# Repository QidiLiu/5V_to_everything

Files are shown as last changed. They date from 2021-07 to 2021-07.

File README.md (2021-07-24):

# 5V_to_everything

Convert *5V (from microUSB)* to various *positive and negative voltages* (for **small currents** only) at low cost with the TPS61040.

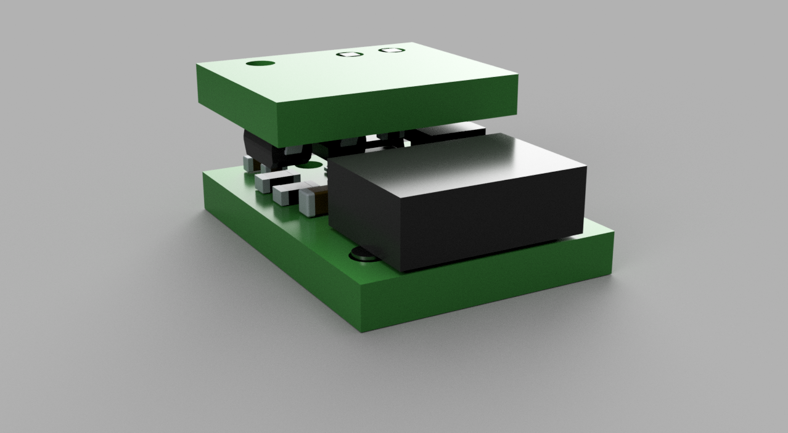
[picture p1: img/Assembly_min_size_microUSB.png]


## Low cost version

### Setting and Usage

Most smartphone chargers can convert 220VAC to 5VDC. With this "5V_to_every" converter, electronic engineers can easily get a positive and negative voltage source, which has an **output voltage from ±5V to ±24V** using their smartphone chargers.

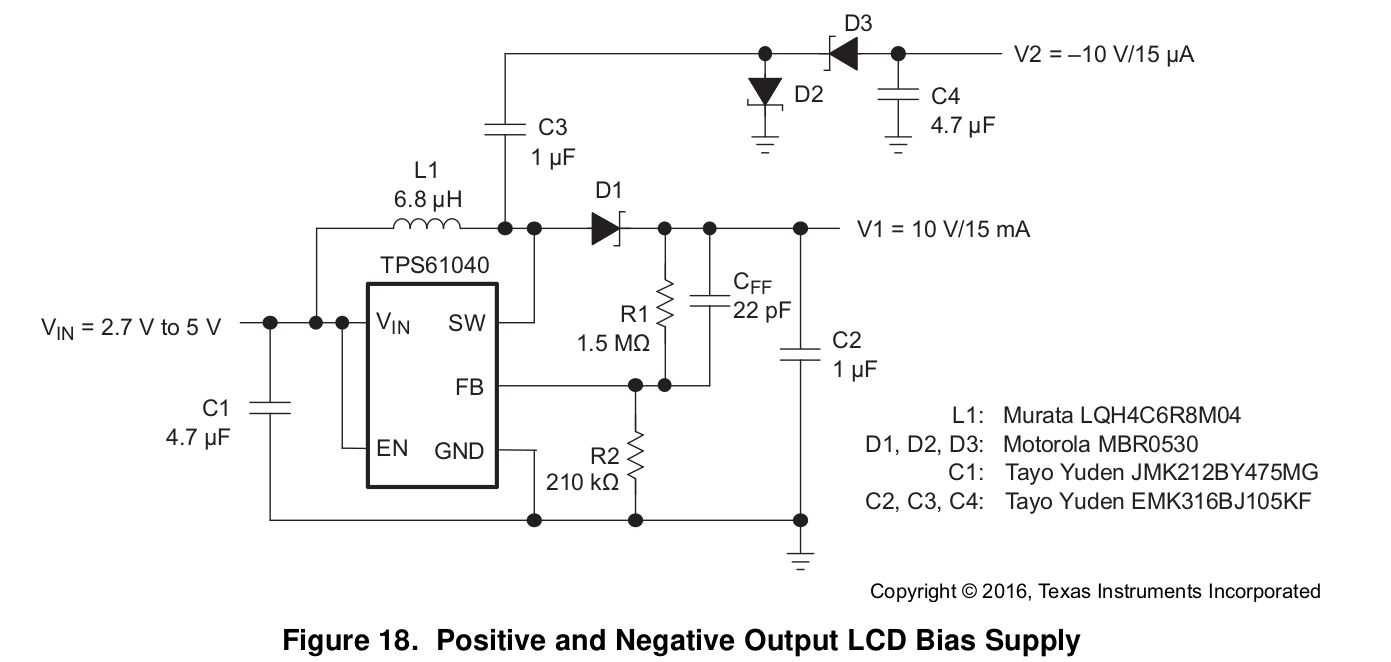
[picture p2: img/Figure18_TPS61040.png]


The basic idea comes from [datasheet of TPS61040](https://www.ti.com/lit/ds/symlink/tps61040.pdf). The output voltage can configured by changing the ratio of R1 to R2. In my design, R2 is 1kΩ SMD resistor and R1 can be easily replaced with a suitable resistor accourding to the calculation:

V_out = 1.233V × (1 + R1/R2) 

(V+ = V_out; V- = -V_out)

(range of V_out: 5V~24V)

For example, if you want a ±10V voltage source:

10 = 1.233 × (1 + R1/1000)

→ R1 = 7110 [Ω]

That means you should replace R1 with a 7.1kΩ resistor.

I also recommend you to replace R1 with a **potentiometer (20kΩ)**, so you can adjust the output voltage directly by hand, and reuse this voltage source in different projects, even when they demand different voltages.

## Minimum size version with microUSB

min_size_microUSB is a minimum size version of 5V_to_everything.

Size of min_size_microUSB[mm]: **14 x 10 x 6**

## Planned versions

- Minimum size version with typeC

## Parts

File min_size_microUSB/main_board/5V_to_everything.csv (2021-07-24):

Reference | Value | Footprint | Datasheet | Description | Height | Manufacturer_Name | Manufacturer_Part_Number | Arrow Part Number | Arrow Price/Stock | Mouser Part Number | Mouser Price/Stock
J1 | MICROXNJ | my_lib:MICROXNJ | https://datasheet.lcsc.com/szlcsc/1912111437_SHOU-HAN-MicroXNJ_C404969.pdf | MICRO-USB-SMD_MICROXNJ | 2.425 | Shou Han | MICROXNJ
C1 | CL10A106MQ8NNNC | my_lib:CAPC1608X90N | http://uk.rs-online.com/web/p/products/7664718 | Samsung Electro-Mechanics 10uF Multilayer Ceramic Capacitor MLCC 6.3V dc +/-20% X5R Dielectric 0603 (1608M) SMD | 0.9 | Samsung Electro-Mechanics | CL10A106MQ8NNNC | CL10A106MQ8NNNC | https://www.arrow.com/en/products/cl10a106mq8nnnc/samsung-electro-mechanics | 187-CL10A106MQ8NNNC | https://www.mouser.co.uk/ProductDetail/Samsung-Electro-Mechanics/CL10A106MQ8NNNC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
L1 | LQH32CN4R7M33L | my_lib:LQH32DN100K23L | https://psearch.en.murata.com/inductor/product/LQH32CN4R7M33%23.html | Murata LQH32CN Series Wire-wound SMD Inductor 4.7 uH +/-20% 650mA Idc | 2.2 | Murata Electronics | LQH32CN4R7M33L | LQH32CN4R7M33L | https://www.arrow.com/en/products/lqh32cn4r7m33l/murata-manufacturing | 81-LQH32CN4R7M33L | https://www.mouser.co.uk/ProductDetail/Murata-Electronics/LQH32CN4R7M33L/?qs=Nd4APhAyBuHM6RzmYPrpQA%3D%3D
D1 | MBR0520L | my_lib:SOD3816X128N | https://www.onsemi.com/pub/Collateral/MBR0520L-D.pdf | ON Semi MBR0520L SMT Schottky Diode, 20V 500mA, 2-Pin SOD-123 | 1.28 | ON Semiconductor | MBR0520L | MBR0520L | https://www.arrow.com/en/products/mbr0520l/on-semiconductor | 512-MBR0520L | https://www.mouser.co.uk/ProductDetail/ON-Semiconductor-Fairchild/MBR0520L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
R2 | 0603WAF1001T5E | my_lib:RESC1608X55N | https://datasheet.lcsc.com/szlcsc/Uniroyal-Elec-0603WAF1001T5E_C21190.pdf | 1k +/-1% 0.1W +/-100ppm/ 0603 Chip Resistor - Surface Mount | 0.55 | UNI-ROYAL(Uniroyal Elec) | 0603WAF1001T5E
C2 | CC0402JRNPO9BN220 | my_lib:CAPC1005X55N | http://www.yageo.com/documents/recent/UPY-GP_NP0_16V-to-50V_16.pdf | YAGEO - CC0402JRNPO9BN220 - CAP, 22PF, 50V, 5%, C0G/NP0, 0402 | 0.55 | YAGEO (PHYCOMP) | CC0402JRNPO9BN220 | CC0402JRNPO9BN220 | https://www.arrow.com/en/products/cc0402jrnpo9bn220/yageo | 603-CC402JRNPO9BN220 | https://www.mouser.co.uk/ProductDetail/Yageo/CC0402JRNPO9BN220?qs=AgBp2OyFlx9i3sVl6vpnFQ%3D%3D
C3 | CL05A105KA5NQNC | my_lib:CAPC1005X60N | https://www.arrow.com/en/products/cl05a105ka5nqnc/samsung-electro-mechanics | Cap Ceramic 1uF 25V X5R 10% Pad SMD 0402 85C T/R | 0.6 | Samsung Electro-Mechanics | CL05A105KA5NQNC | CL05A105KA5NQNC | https://www.arrow.com/en/products/cl05a105ka5nqnc/samsung-electro-mechanics | 187-CL05A105KA5NQNC | https://www.mouser.co.uk/ProductDetail/Samsung-Electro-Mechanics/CL05A105KA5NQNC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
IC1 | TPS61040DBVR | my_lib:SOT95P280X145-5N | http://www.ti.com/lit/ds/symlink/tps61040.pdf | Switch Boost Converter 28V 400mA for LCD Texas Instruments TPS61040DBVR, Step Up DC-DC Converter, 550mA, Adjustable, 1.8 ??? 28 V, 5-Pin SOT-23 | 1.45 | Texas Instruments | TPS61040DBVR | TPS61040DBVR | https://www.arrow.com/en/products/tps61040dbvr/texas-instruments | 595-TPS61040DBVR | https://www.mouser.co.uk/ProductDetail/Texas-Instruments/TPS61040DBVR?qs=Gse6rAGbi78IU3cZg2VK0g%3D%3D
R1 | 0603WAF1001T5E | my_lib:RESC1608X55N | https://datasheet.lcsc.com/szlcsc/Uniroyal-Elec-0603WAF1001T5E_C21190.pdf | 1k +/-1% 0.1W +/-100ppm/ 0603 Chip Resistor - Surface Mount | 0.55 | UNI-ROYAL(Uniroyal Elec) | 0603WAF1001T5E
J2 | Du_Pont_pin | my_lib:Du_Pont_pin
J3 | Du_Pont_pin | my_lib:Du_Pont_pin
J4 | Du_Pont_pin | my_lib:Du_Pont_pin

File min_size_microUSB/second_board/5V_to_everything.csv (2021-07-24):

Reference | Value | Footprint | Datasheet | Arrow Part Number | Arrow Price/Stock | Description | Height | Manufacturer_Name | Manufacturer_Part_Number | Mouser Part Number | Mouser Price/Stock
C1 | CL05A105KA5NQNC | my_lib:CAPC1005X60N | https://www.arrow.com/en/products/cl05a105ka5nqnc/samsung-electro-mechanics | CL05A105KA5NQNC | https://www.arrow.com/en/products/cl05a105ka5nqnc/samsung-electro-mechanics | Cap Ceramic 1uF 25V X5R 10% Pad SMD 0402 85C T/R | 0.6 | Samsung Electro-Mechanics | CL05A105KA5NQNC | 187-CL05A105KA5NQNC | https://www.mouser.co.uk/ProductDetail/Samsung-Electro-Mechanics/CL05A105KA5NQNC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
D2 | MBR0520L | my_lib:SOD3816X128N | https://www.onsemi.com/pub/Collateral/MBR0520L-D.pdf | MBR0520L | https://www.arrow.com/en/products/mbr0520l/on-semiconductor | ON Semi MBR0520L SMT Schottky Diode, 20V 500mA, 2-Pin SOD-123 | 1.28 | ON Semiconductor | MBR0520L | 512-MBR0520L | https://www.mouser.co.uk/ProductDetail/ON-Semiconductor-Fairchild/MBR0520L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
D1 | MBR0520L | my_lib:SOD3816X128N | https://www.onsemi.com/pub/Collateral/MBR0520L-D.pdf | MBR0520L | https://www.arrow.com/en/products/mbr0520l/on-semiconductor | ON Semi MBR0520L SMT Schottky Diode, 20V 500mA, 2-Pin SOD-123 | 1.28 | ON Semiconductor | MBR0520L | 512-MBR0520L | https://www.mouser.co.uk/ProductDetail/ON-Semiconductor-Fairchild/MBR0520L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
C2 | CL05A105KA5NQNC | my_lib:CAPC1005X60N | https://www.arrow.com/en/products/cl05a105ka5nqnc/samsung-electro-mechanics | CL05A105KA5NQNC | https://www.arrow.com/en/products/cl05a105ka5nqnc/samsung-electro-mechanics | Cap Ceramic 1uF 25V X5R 10% Pad SMD 0402 85C T/R | 0.6 | Samsung Electro-Mechanics | CL05A105KA5NQNC | 187-CL05A105KA5NQNC | https://www.mouser.co.uk/ProductDetail/Samsung-Electro-Mechanics/CL05A105KA5NQNC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
J3 | Du_Pont_pin | my_lib:Du_Pont_pin
J2 | Du_Pont_pin | my_lib:Du_Pont_pin
J1 | Du_Pont_pin | my_lib:Du_Pont_pin

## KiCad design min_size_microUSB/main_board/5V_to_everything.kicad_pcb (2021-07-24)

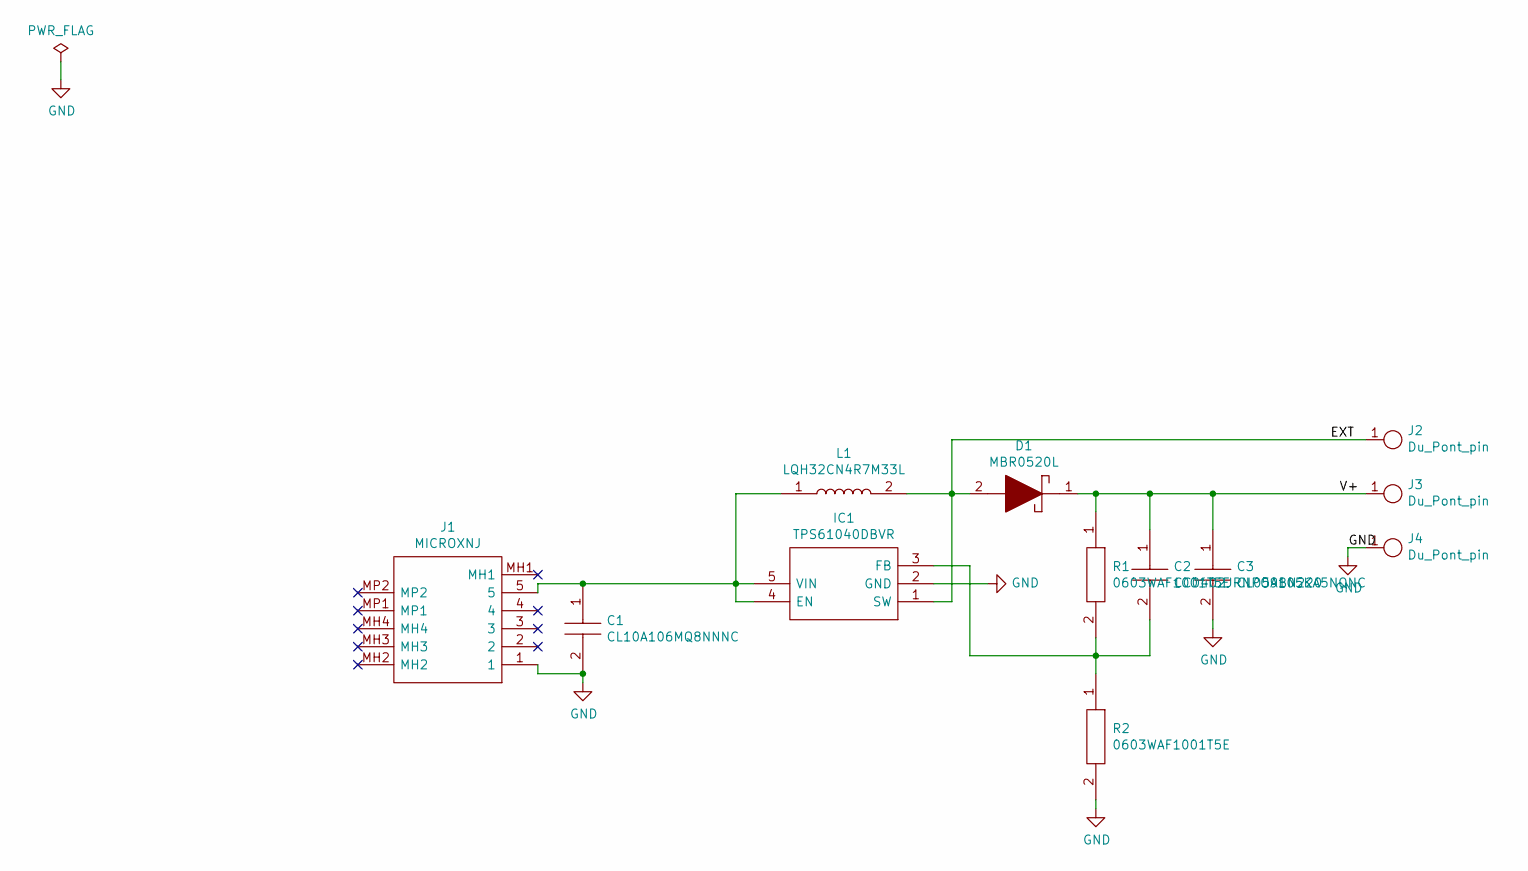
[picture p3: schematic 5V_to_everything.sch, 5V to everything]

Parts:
C1: CL10A106MQ8NNNC; CAPC1608X90N; Manufacturer_Part_Number CL10A106MQ8NNNC; Mouser Part Number 187-CL10A106MQ8NNNC
C2: CC0402JRNPO9BN220; CAPC1005X55N; Manufacturer_Part_Number CC0402JRNPO9BN220; Mouser Part Number 603-CC402JRNPO9BN220
C3: CL05A105KA5NQNC; CAPC1005X60N; Manufacturer_Part_Number CL05A105KA5NQNC; Mouser Part Number 187-CL05A105KA5NQNC
D1: MBR0520L; SOD3816X128N; Manufacturer_Part_Number MBR0520L; Mouser Part Number 512-MBR0520L
IC1: TPS61040DBVR; SOT95P280X145-5N; Manufacturer_Part_Number TPS61040DBVR; Mouser Part Number 595-TPS61040DBVR
J1: MICROXNJ; Manufacturer_Part_Number MICROXNJ
J2, J3, J4: Du_Pont_pin
L1: LQH32CN4R7M33L; LQH32DN100K23L; Manufacturer_Part_Number LQH32CN4R7M33L; Mouser Part Number 81-LQH32CN4R7M33L
R1, R2: 0603WAF1001T5E; RESC1608X55N; Manufacturer_Part_Number 0603WAF1001T5E

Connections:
/EXT: D1.2, IC1.1 (SW), J2.1, L1.2
/V+: C2.1, C3.1, D1.1, J3.1, R1.1
GND: C1.2, C3.2, IC1.2 (GND), J1.1, J4.1, R2.2
unnamed: C1.1, IC1.4 (EN), IC1.5 (VIN), J1.5, L1.1
unnamed: C2.2, IC1.3 (FB), R1.2, R2.1

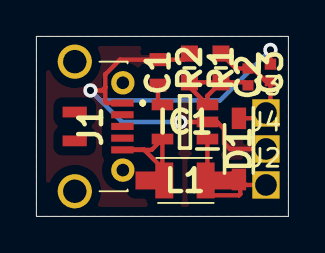
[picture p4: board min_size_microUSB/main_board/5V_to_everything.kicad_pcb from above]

Board: 2 copper layers, 14.0 x 10.0 mm, 12 parts (0 on the bottom side), 5 nets.

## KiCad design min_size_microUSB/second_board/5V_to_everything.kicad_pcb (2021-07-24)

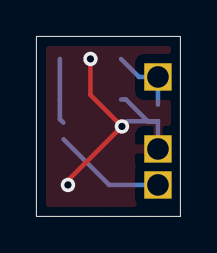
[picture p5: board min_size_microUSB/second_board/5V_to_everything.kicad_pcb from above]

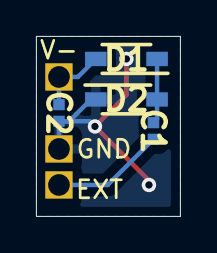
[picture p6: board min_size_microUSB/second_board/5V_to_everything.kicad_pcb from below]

Board: 2 copper layers, 8.0 x 10.0 mm, 7 parts (7 on the bottom side), 4 nets.

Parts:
C1, C2: CL05A105KA5NQNC; CAPC1005X60N
D1, D2: MBR0520L; SOD3816X128N
EXT: Du_Pont_pin
GND: Du_Pont_pin
V-: Du_Pont_pin

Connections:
GND: C2.2, D2.1, GND.1
unnamed: C1.1, D1.1, D2.2
unnamed: C1.2, EXT.1
unnamed: C2.1, D1.2, V-.1

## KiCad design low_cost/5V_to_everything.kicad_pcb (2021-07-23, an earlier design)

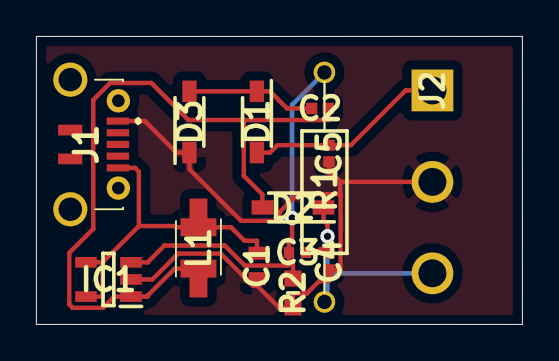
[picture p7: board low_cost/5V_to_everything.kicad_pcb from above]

Board: 2 copper layers, 27.0 x 16.0 mm, 14 parts (0 on the bottom side), 7 nets.

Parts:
C1: CL10A106MQ8NNNC; CAPC1608X90N
C2, C4, C5: CL05A105KA5NQNC; CAPC1005X60N
C3: CC0402JRNPO9BN220; CAPC1005X55N
D1, D2, D3: MBR0520L; SOD3816X128N
IC1: TPS61040DBVR; SOT95P280X145-5N
J1: MICROXNJ
J2: WJ500V-5.08-3P; SHDR3W95P0X508_1X3_1524X1000X1420P
L1: LQH32CN4R7M33L; LQH32DN100K23L
R1: MFR0W4F1001A50; RESAD1680W62L680D250
R2: 0603WAF1001T5E; RESC1608X55N

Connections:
/V+: C3.1, C4.1, D2.1, J2.3, R1.1
/V-: C5.1, D1.2, J2.1
GND: C1.2, C4.2, C5.2, D3.1, IC1.2, J1.1, J2.2, R2.2
unnamed: C1.1, IC1.4, IC1.5, J1.5, L1.1
unnamed: C2.1, D1.1, D3.2
unnamed: C2.2, D2.2, IC1.1, L1.2
unnamed: C3.2, IC1.3, R1.2, R2.1
